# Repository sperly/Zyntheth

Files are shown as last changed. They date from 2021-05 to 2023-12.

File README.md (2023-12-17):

# Zynthethet
The Zyntheth will be a 4-6 operator 16 voices FM synthesis synth. It will have DIN-5 MIDI In, Thru and Out (from the Arpeggio). It will also have a USB-based Midi interface. There will also be support for Ethernet based RTP-MIDI.

It will have a stereo output (3.5mm plug) and it is powered by a regular micro-USB phone charger (500mA is enough). The user interface is a 3.5 inch touch LCD and 5 rotary encoders.

# Hardware
The hardware consists of 5 different pcb's:

The power board, takes the power from the micro-USB and converts it to 3.3v for other modules to run on.
The UI board, has the display and a connection for 1 encoder board with 5 encoders. It also has a Teensy 4.1 micro controller with 8Mb extra flash for graphics.
The Audio board, is the audio generator board with a Teensy 4.1 with 16Mb added PSRAM for additional effects usage.
The Interface board, has an Teensy 4.1 with ethernet interface added. This board takes care of all signals in and out from the Zyntheth (apart from the audio signals). It will also take care of arpeggio note generation.
Encoder board, a board with 5 rotary encoder and a button fitted to it. It has a SPI interface connection to the UI board.

# Functionality
4-6 operators (similar to DX9/DX7) FM synthesis in multiple algorithmic configuration
Individual envelope for each operator
Configurable detune, volume, panning for each operator
General envelope
Filter, 5-band parametric equlizer
Multiple effects: chorus, reverb, echo/delay, BitChrusher, Granular, etc.
Dual configurable LFO, either frequency, detune och volume
Configurable midi channel

# Todo
Add USB Audio output.

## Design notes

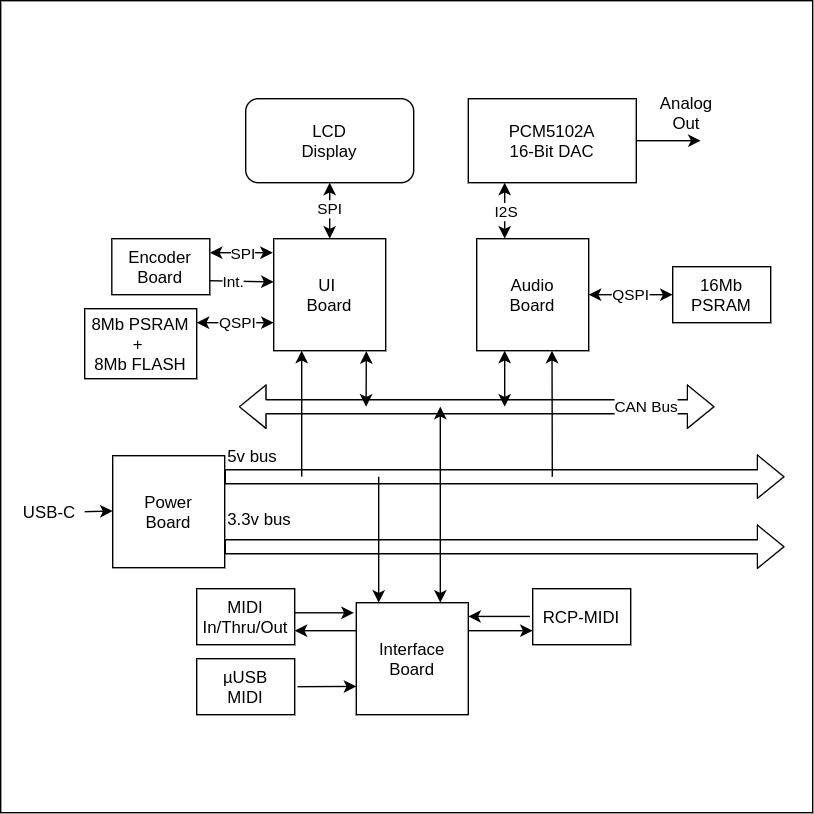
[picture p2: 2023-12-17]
Graphics/Zyntheth.png

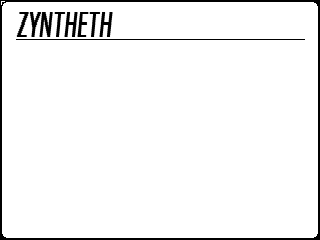
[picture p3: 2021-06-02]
Graphics/main.bmp

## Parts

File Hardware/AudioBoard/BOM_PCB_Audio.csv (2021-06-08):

ID | Name | Designator | Footprint | Quantity | Manufacturer Part | Manufacturer | Supplier | Supplier Part | Price | JLCPCB Part Class
1 | 2.2µF | C1,C2 | CASE-A_3216 | 2 | CL10A225KO8NNNC | SAMSUNG | LCSC | C23630 | 0.0092
2 | 100µF | C3,C4 | ECAP_5X5.4 | 2 | RVT1A101M0505 | HONOR | LCSC | C3347 | 0.041
3 | 1u | C6 | CASE-A_3216 | 1 | CL31B105KBHNNNE | SAMSUNG | LCSC | C1848 | 0.0386
4 | 0.1uF | C5,C7 | CASE-A_3216 | 2 | CC0603KRX7R9BB104 | YAGEO | LCSC | C14663 | 0.0041
5 | PJ-307G5 | CN1,CN2 | AUDIO-TH_PJ-307G5 | 2 | PJ-307G5 | XKB Enterprise | LCSC | C381128 | 0.1643 | Extended Part
6 | SS12 | D3 | SMA_L4.3-W2.6-LS5.2-RD | 1 | SS12 | MDD | LCSC | C2479 | 0.0354 | Extended Part
7 | Hole | HOL1,HOL2,HOL3,HOL4 | 3.5MM HOLE | 4
8 | 1X2 | J3 | HDR-TH_2P-P2.54-V | 1 | 210-91-02GB01 | PINREX | LCSC | C390678 | 0.0083
9 | Header-Female-2.54_1x11 | P1 | PIN_HEADER_STRAIGHT_1X11_PITCH2.54MM | 1 | Female header 2.54-1*11P | BOOMELE | LCSC | C52709 | 0.101
10 | Header-Male-2.54_1x3 | P2 | HDR-3X1/2.54 | 1 | Header-Male-2.54_1x3 | LCSC | LCSC | C49257 | 0.0171
11 | Header-Female-2.54_1x2 | P3,P4 | HDR-TH_2P-P2.54-V-M | 2 | 2.54-1*2PFemale | BOOMELE | LCSC | C49661 | 0.0321 | Extended Part
12 | 100k | R1,R7 | R0603 | 2 | CMFA104F4150HANT | FH | LCSC | C71448 | 0.0587
13 | 3k9 | R2,R3,R4,R6 | R0603 | 4 | 0603WAF3901T5E | UniOhm | LCSC | C23018 | 0.0015
14 | 220 | R9 | R0603 | 1 | 0603WAF2200T5E | UniOhm | LCSC | C22962 | 0.0015
15 | Teensy 4.1 | U1 | TEENSY 4.1 | 1 | TEENSY41 | pjrc | pimoroni | TEENSY41
16 | LM4808MX/NOPB | U2 | SOIC-8_L4.9-W3.9-P1.27-LS6.0-BL-2 | 1 | LM4808MX/NOPB | Texas Instruments | LCSC | C141374 | 0.6925 | Extended Part

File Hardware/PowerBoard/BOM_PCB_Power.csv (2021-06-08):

ID | Name | Designator | Footprint | Quantity | Manufacturer Part | Manufacturer | Supplier | Supplier Part | Price | JLCPCB Part Class
1 | 1u | C1,C2 | CASE-A_3216 | 2 | CL21B105KBFNNNE | SAMSUNG | LCSC | C28323 | 0.0143
2 | HDR-F-2.54_2x2 | H1 | HDR-F-2.54_2X2 | 1 |  |  | LCSC | C239342 | 0.0854
3 | HDR-F-2.54_1x2 | H2,H3,H4,H5,H6,H7 | HDR-F-2.54_1X2 | 6 |  |  | LCSC | C49661 | 0.0321
4 | Hole | HOL1,HOL2,HOL3,HOL4 | 3.5MM HOLE | 4
5 | LM1117MPX-3.3/NOPB | U2 | SOT-223-3_L6.5-W3.4-P2.30-LS7.0-BR | 1 | LM1117MPX-3.3/NOPB | TI | LCSC | C9662 | 0.5104 | Extended Part
6 | TYPE-C-31-M-17 | USB1 | USB-C-SMD_10P-P1.00-L6.8-W8.9 | 1 | TYPE-C-31-M-17 | Korean Hroparts Elec | LCSC | C283540 | 0.2146 | Extended Part

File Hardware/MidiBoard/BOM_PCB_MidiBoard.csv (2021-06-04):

ID | Name | Designator | Footprint | Quantity | Manufacturer Part | Manufacturer | Supplier | Supplier Part | Price | JLCPCB Part Class
1 | 100n | C1 | C0603 | 1 | CC0603KRX7R9BB104 | YAGEO | LCSC | C14663 | 0.0041
2 | 100n | C2,C3 | C0603 | 2 | CC0603KRX7R9BB104 | YAGEO | LCSC | C14663 | 0.0041
3 | 100n | C4 | C0603 | 1 | CC0603KRX7R9BB104 | YAGEO | LCSC | C14663 | 0.0041
4 | 1N4004 | D1 | SOD-123_L2.8-W1.8-LS3.7-RD | 1 | 1N4004W | Jingdao | LCSC | C162734 | 0.0104
5 | USBLC6-2SC6 | D2 | SOT-23-6_L2.9-W1.6-P0.95-LS2.8-BR | 1 | USBLC6-2SC6 | STMicroelectronics | LCSC | C7519 | 0.3978 | Extended Part
6 | SS12 | D3 | SMA_L4.3-W2.6-LS5.2-RD | 1 | SS12 | MDD | LCSC | C2479 | 0.0354 | Extended Part
7 | HDR-F-2.54_1x2 | H1 | HDR-F-2.54_1X2 | 1 | 826629-2 | TE Connectivity | LCSC | C86471 | 0.1458
8 | Hole | HOL1,HOL2,HOL3,HOL5,HOL6 | 3.5MM HOLE | 5
9 | 1X2 | J1,J2 | HDR-TH_2P-P2.54-V | 2 | 826629-2 | TE Connectivity | LCSC | C86471 | 0.1458
10 | LED-0603_R | LED1 | LED0603_RED | 1 | 19-217/R6C-AL1M2VY/3T | EVERLIGHT(台湾亿光) | LCSC | C72044 | 0.0157
11 | 330 | R1 | R0603 | 1 | 0603WAF3300T5E | UniOhm | LCSC | C23138 | 0.0015
12 | 220 | R2,R3,R5,R7,R8,R9 | R0603 | 6 | 0603WAF2200T5E | UniOhm | LCSC | C22962 | 0.0015
13 | 470 | R4,R10 | R0603 | 2 | 0603WAF4700T5E | UniOhm | LCSC | C23179 | 0.0017
14 | 4k7 | R6 | R0603 | 1 | 0603WAF4701T5E | UniOhm | LCSC | C23162 | 0.0014
15 | 13F-60FGYDPNW2NL | RJ1 | RJ45-TH_13F-60FGYDPNW2NL | 1 | 13F-60FGYDPNW2NL | YDS | LCSC | C115955 | 2.1964 | Extended Part
16 | MIDI OUT | U2 | MIDI | 1
17 | 1 | U3 | TEENSY4.1 - KB | 1 | Teensy4.1 | PJRC
18 | 74HCT14D,653 | U4 | SOIC-14_L8.7-W3.9-P1.27-LS6.0-BL | 1 | 74HCT14D,653 | Nexperia | LCSC | C5967 | 0.1389 | Extended Part
19 | 6N138-L | U5 | DIP-8_L9.7-W6.4-P2.54-LS7.6-BL | 1 | 6N138-L | Lite-On | LCSC | C571211 | 0.422 | Extended Part
20 | MIDI IN | U6 | MIDI | 1
21 | MIDI THRU | U7 | MIDI | 1
22 | MICRO XNJ ZB | USB1 | MICRO-USB-SMD_MICRO-XNJ-ZB | 1 | MICRO XNJ ZB | SHOU HAN(首韩) | LCSC | C668587 | 0.0587

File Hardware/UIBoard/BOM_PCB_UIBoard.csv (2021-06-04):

ID | Name | Designator | Footprint | Quantity | Manufacturer Part | Manufacturer | Supplier | Supplier Part | Price | JLCPCB Part Class | Paste Type
1 | CR1220-2ZX | BT1 | BAT-SMD_CR1220-2ZX | 1 | CR1220-2ZX | Q&J | LCSC | C969906 | 0.2763 | Extended Part | Extended Part
2 | SS12 | D1 | SMA_L4.3-W2.6-LS5.2-RD | 1 | SS12 | MDD | LCSC | C2479 | 0.0354 | Extended Part
3 | Header-Male-2.54_2x5 | H1 | HDR-TH_10P-P2.54-V-R2-C5-S2.54 | 1 | IDC Box 2X5 2.54MM | BOOMELE | LCSC | C9140 | 0.0865
4 | Header-Female-2.54_1x4 | H2 | HDR-4X1/2.54 | 1 | Header-Female-2.54_1x4 | ReliaPro | LCSC | C124413 | 0.0943
5 | J-Header-Male-2.54_1x2 | H3,H4 | HDR-2X1/2.54 | 2 | 826629-2 | TE Connectivity | LCSC | C86471 | 0.1458
6 | 1X2 | H5 | HDR-TH_2P-P2.54-V | 1 | 210-91-02GB01 | PINREX | LCSC | C390678 | 0.0083
7 | M11 | H6 | 1X11_LOCK | 1
8 | Hole | HOL1,HOL2,HOL3,HOL4 | 3.5MM HOLE | 4
9 | 220 | R1 | R0603 | 1 | 0603WAF2200T5E | UniOhm | LCSC | C22962 | 0.0015
10 | 10k | R2 | R0603 | 1 | 0603WAF1002T5E | UniOhm | LCSC | C25804 | 0.0014
11 | teensy_Teensy3.6_1 | U1 | TEENSY35_36 | 1

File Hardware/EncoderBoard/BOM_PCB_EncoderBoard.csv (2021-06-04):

ID | Name | Designator | Footprint | Quantity | Manufacturer Part | Manufacturer | Supplier | Supplier Part | Price | JLCPCB Part Class
1 | 10nF | C1,C2,C3,C4,C5,C6,C7,C8,C9,C10 | C0603 | 10 | CL10B103JB8NNNC | SAMSUNG | LCSC | C7248 | 0.0084
2 | 0.1u | C11 | C0603 | 1 | CL10B104JB8NNNC | SAMSUNG | LCSC | C24452 | 0.0086
3 | Header-Male-2.54_2x5 | H1 | HDR-TH_10P-P2.54-V-R2-C5-S2.54 | 1 | IDC Box 2.54mm 2X5P | BOOMELE | LCSC | C5665 | 0.0652
4 | 10k | R1,R2,R3,R4,R5,R6,R7,R8,R9,R10,R11,R12,R13,R14,R15,R16,R17,R18,R19,R20,R21,R22,R23,R24,R25,R26,R27 | R0603 | 27 | SDNT1608X103F3450FTF | Sunlord | LCSC | C95953 | 0.0386
5 | PEC11R-4015F-S0024 | SW1,SW2,SW3,SW4,SW5 | SW-TH_PEC11R-4XXXF-SXXXX | 5 | PEC11R-4015F-S0024 | BOURNS | LCSC | C143789 | 1.8394 | Extended Part
6 | K2-1102SP-C4SC-04 | SW6 | KEY-SMD_4P-L6.0-W6.0-P4.50-LS9.5-BL | 1 | K2-1102SP-C4SC-04 | HRO | LCSC | C127509 | 0.0479 | Extended Part
7 | MCP23S17-E/ML | U2 | QFN-28_L6.0-W6.0-P0.65-BL-EP | 1 | MCP23S17-E/ML | MICROCHIP | LCSC | C147896 | 3.071 | Extended Part

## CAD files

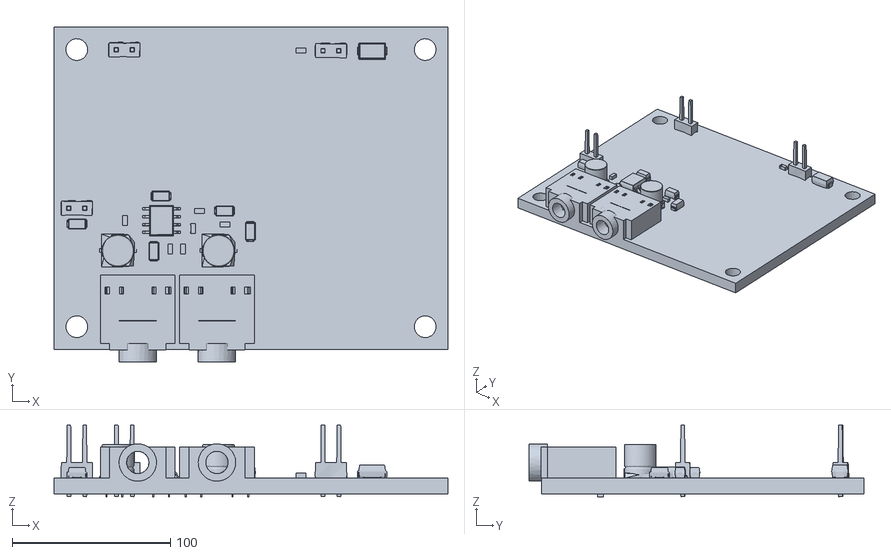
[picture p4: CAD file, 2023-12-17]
Hardware/AudioBoard/PCB_Zyntheth-Audio.stl
248.8 x 211.8 x 45.2

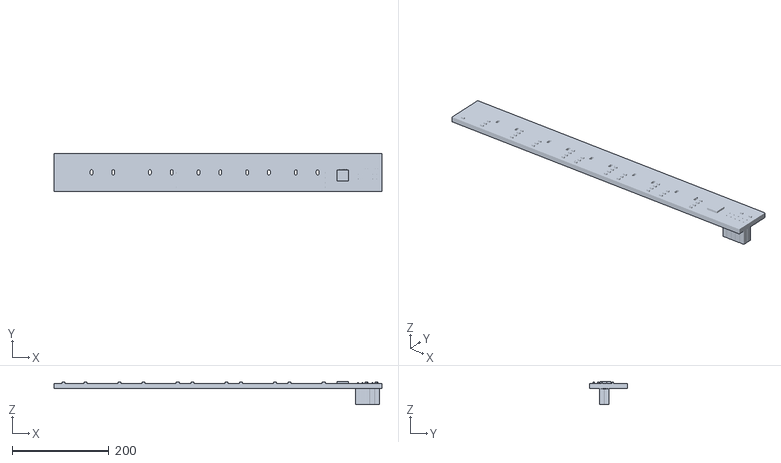
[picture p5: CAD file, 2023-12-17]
Hardware/EncoderBoard/PCB_EncoderBoard.stl
676.8 x 77.5 x 47.5

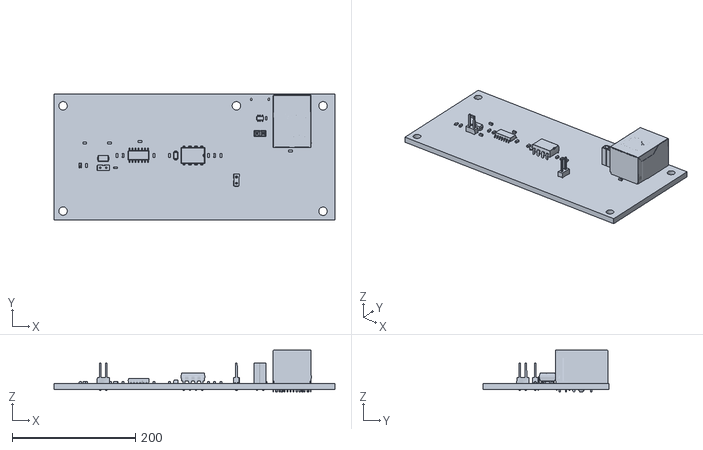
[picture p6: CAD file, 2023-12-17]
Hardware/MidiBoard/OBJ_PCB_Zyntheth-Midi-teensy.obj
455.8 x 204.8 x 67.6

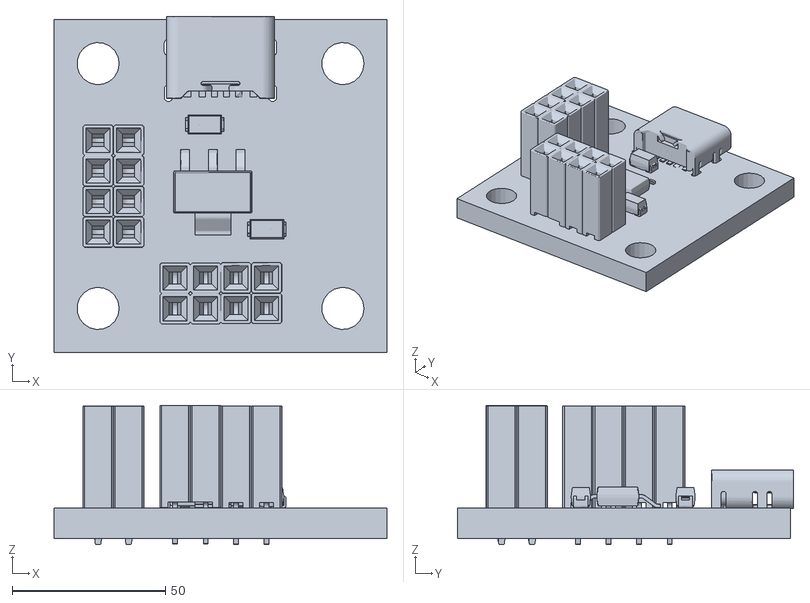
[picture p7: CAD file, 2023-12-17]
Hardware/PowerBoard/OBJ_PCB_Zynthet-Power.obj
108.8 x 109.8 x 45.5

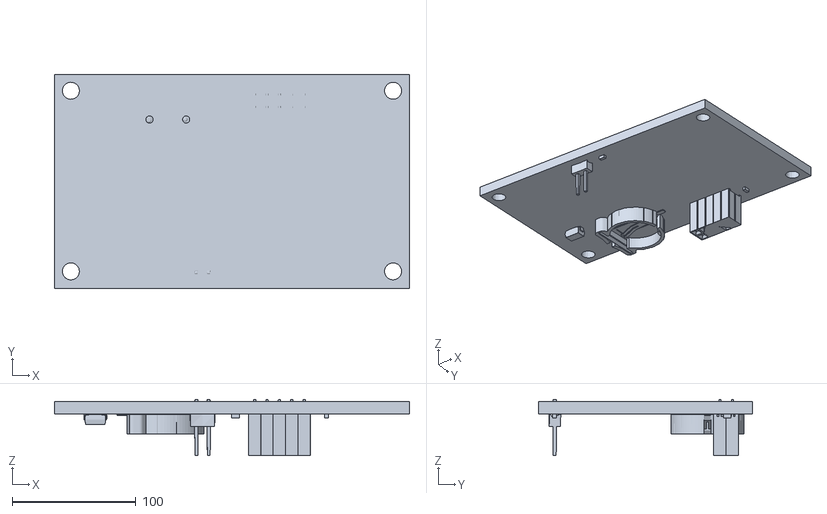
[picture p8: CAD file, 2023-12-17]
Hardware/UIBoard/PCB_UIBoard.stl
286.3 x 172.8 x 45.3

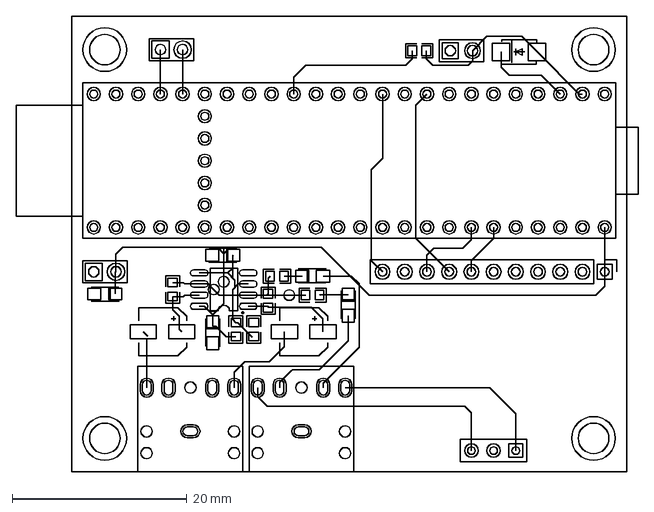
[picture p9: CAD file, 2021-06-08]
Hardware/AudioBoard/PCB_Audio.dxf
71.1 x 52.1 mm

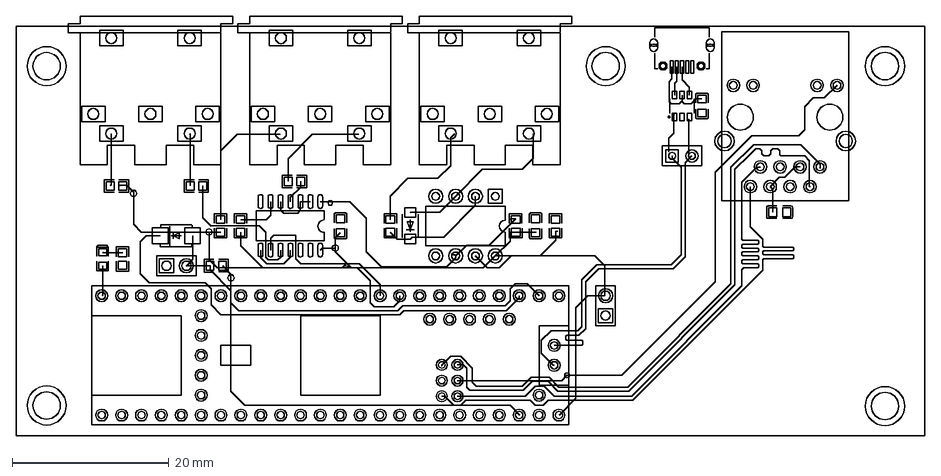
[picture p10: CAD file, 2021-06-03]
Hardware/MidiBoard/PCB_MidiBoard.dxf
116.1 x 53.6 mm

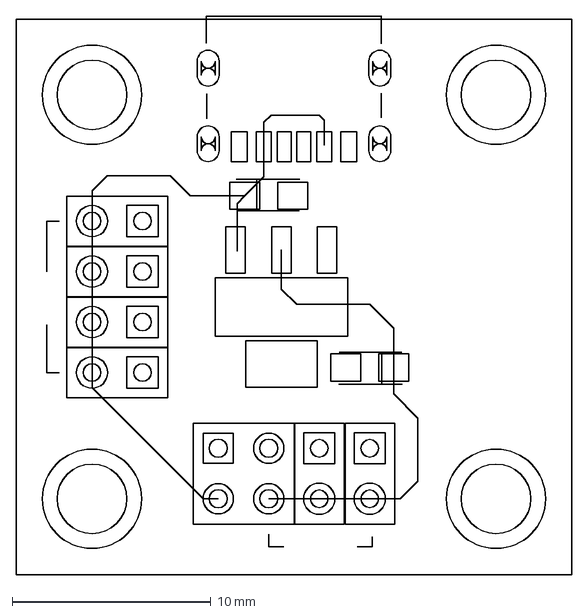
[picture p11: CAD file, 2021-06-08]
Hardware/PowerBoard/PCB_Power.dxf
27.9 x 28.1 mm

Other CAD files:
Hardware/AudioBoard/OBJ_PCB_Zyntheth-Audio.obj
Hardware/EncoderBoard/OBJ_PCB_EncoderBoard.obj
Hardware/MidiBoard/PCB_Zyntheth-Midi-teensy.stl
Hardware/PowerBoard/PCB_Zynthet-Power.stl
Hardware/UIBoard/OBJ_PCB_UIBoard.obj
Hardware/EncoderBoard/PCB_EncoderBoard.dxf
Hardware/UIBoard/PCB_UIBoard.dxf

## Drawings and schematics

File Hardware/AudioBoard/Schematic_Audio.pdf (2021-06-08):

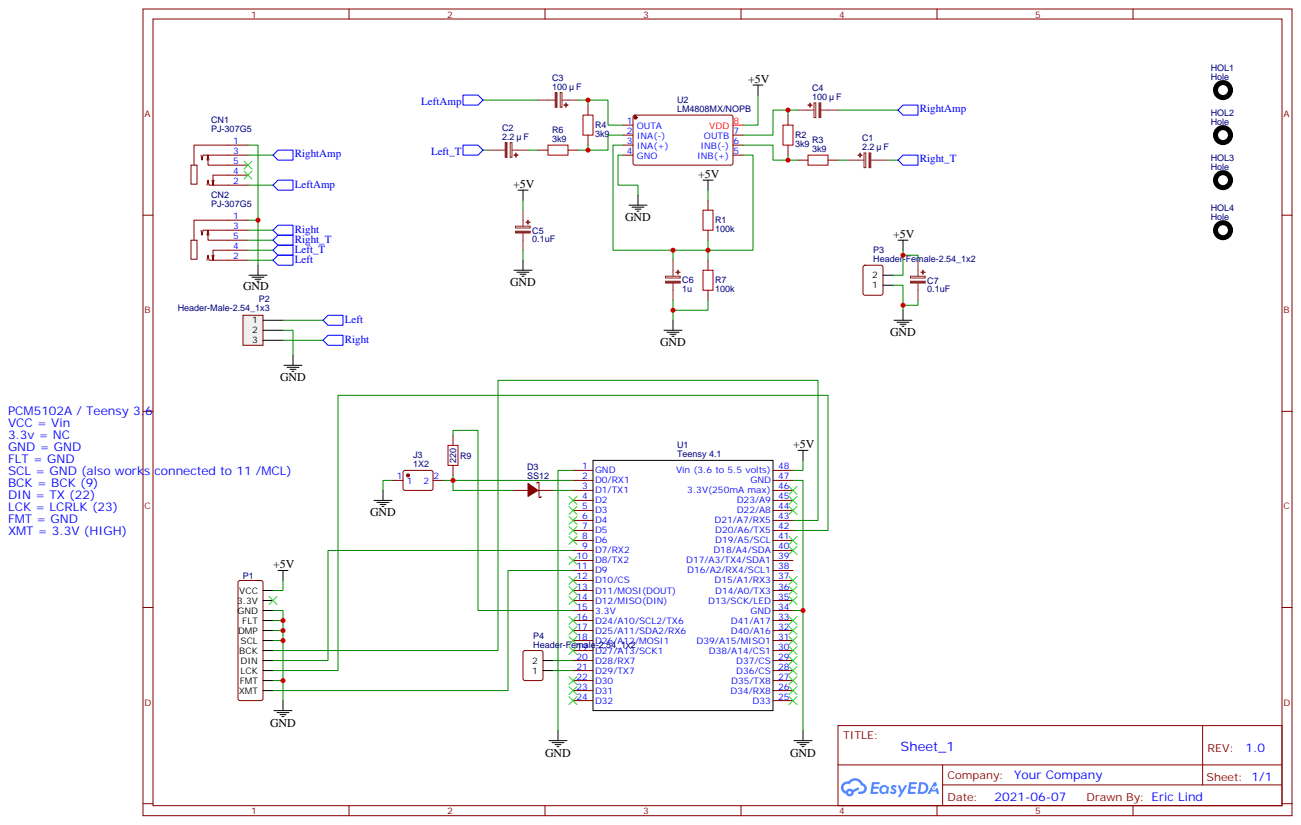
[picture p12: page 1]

PCM5102A / Teensy 3.6
VCC = Vin
GND = GND
FLT = GND
SCL = GND (also works connected to 11 /MCL)
BCK = BCK (9)
DIN = TX (22)
LCK = LCRLK (23)
FMT = GND
XMT = 3.3V (HIGH)

Drawn By: Eric Lind

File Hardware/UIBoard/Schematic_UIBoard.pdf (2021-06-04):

## Hole

## HOL1

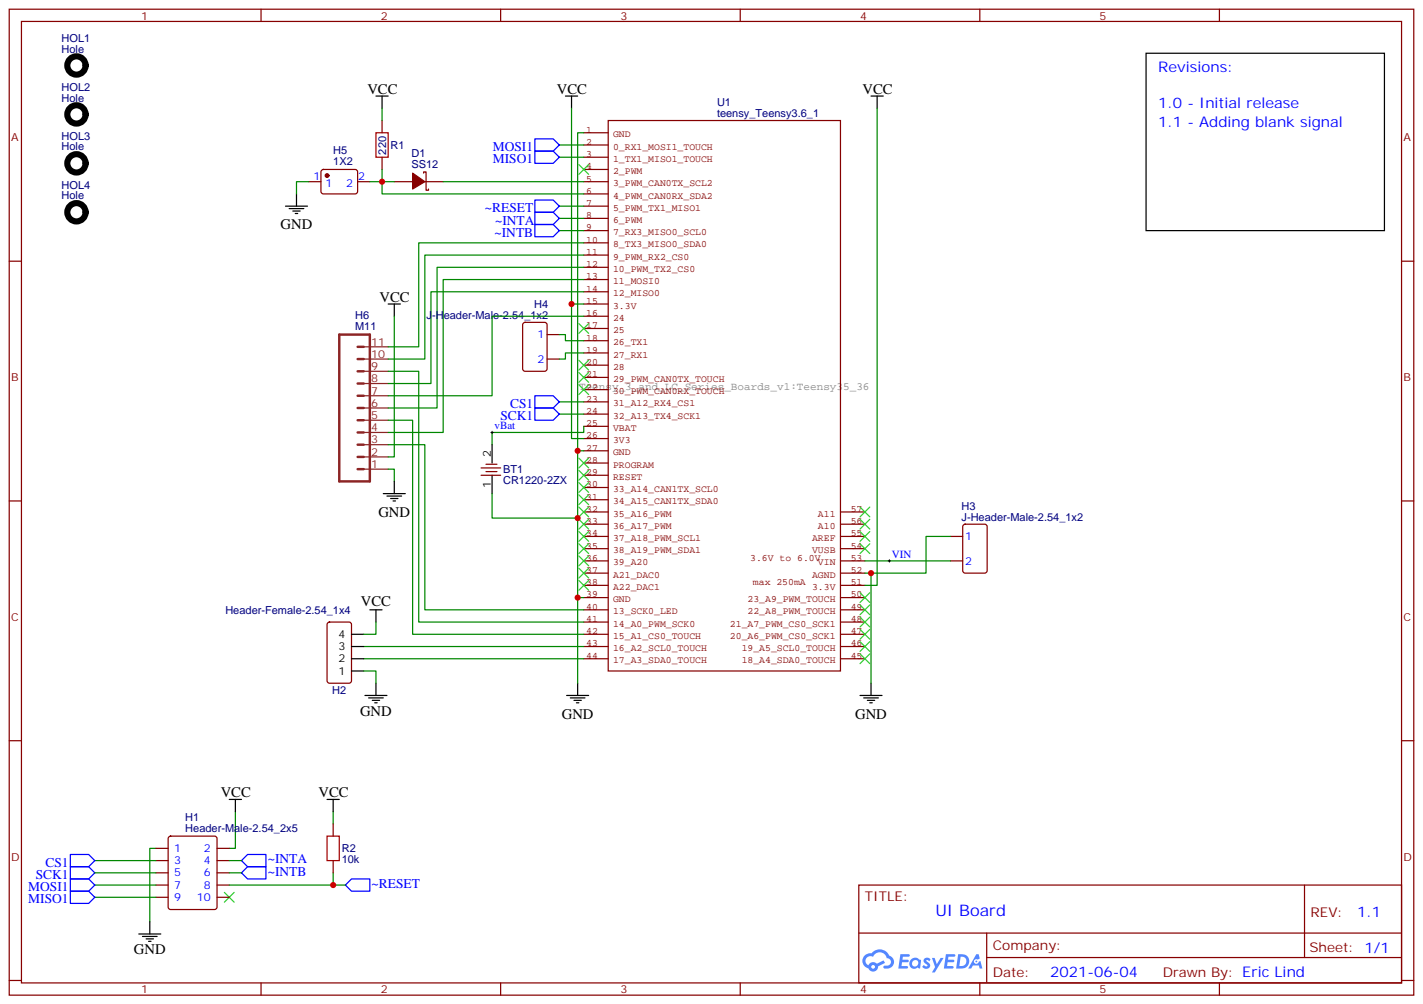
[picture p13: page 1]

Drawn By: Eric Lind

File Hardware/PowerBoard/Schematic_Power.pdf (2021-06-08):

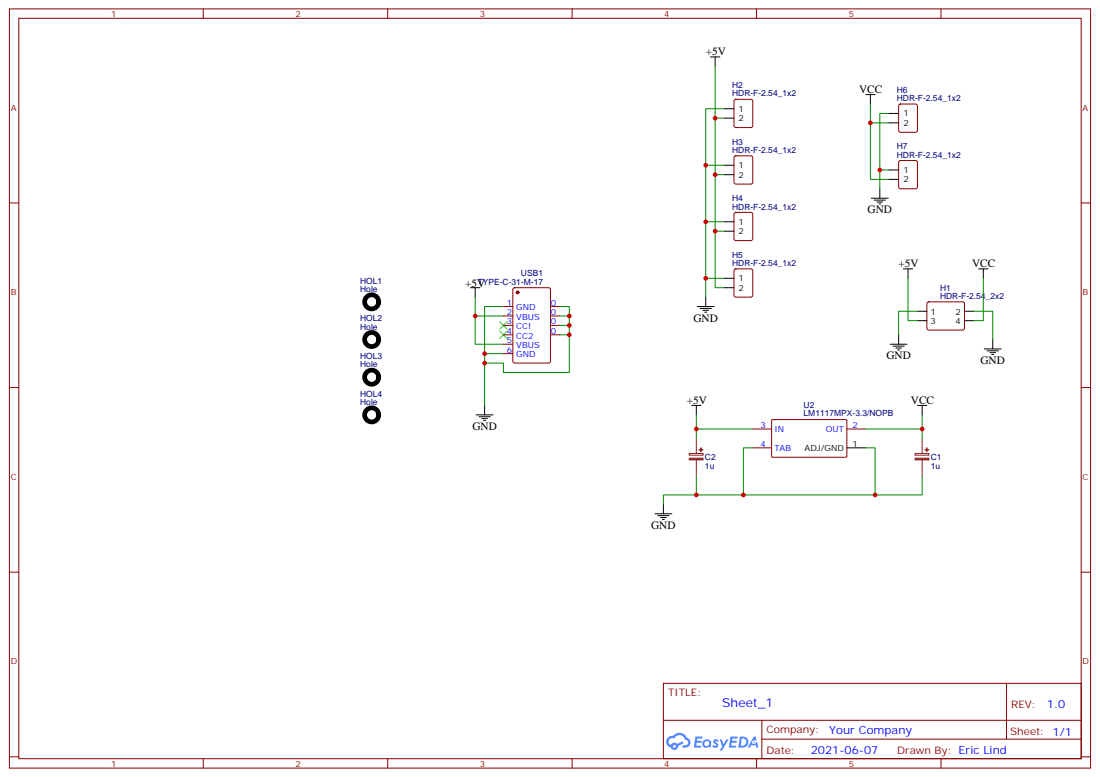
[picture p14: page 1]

Drawn By: Eric Lind

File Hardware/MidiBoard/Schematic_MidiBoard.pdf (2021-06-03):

## 74HCT14D,653

U4

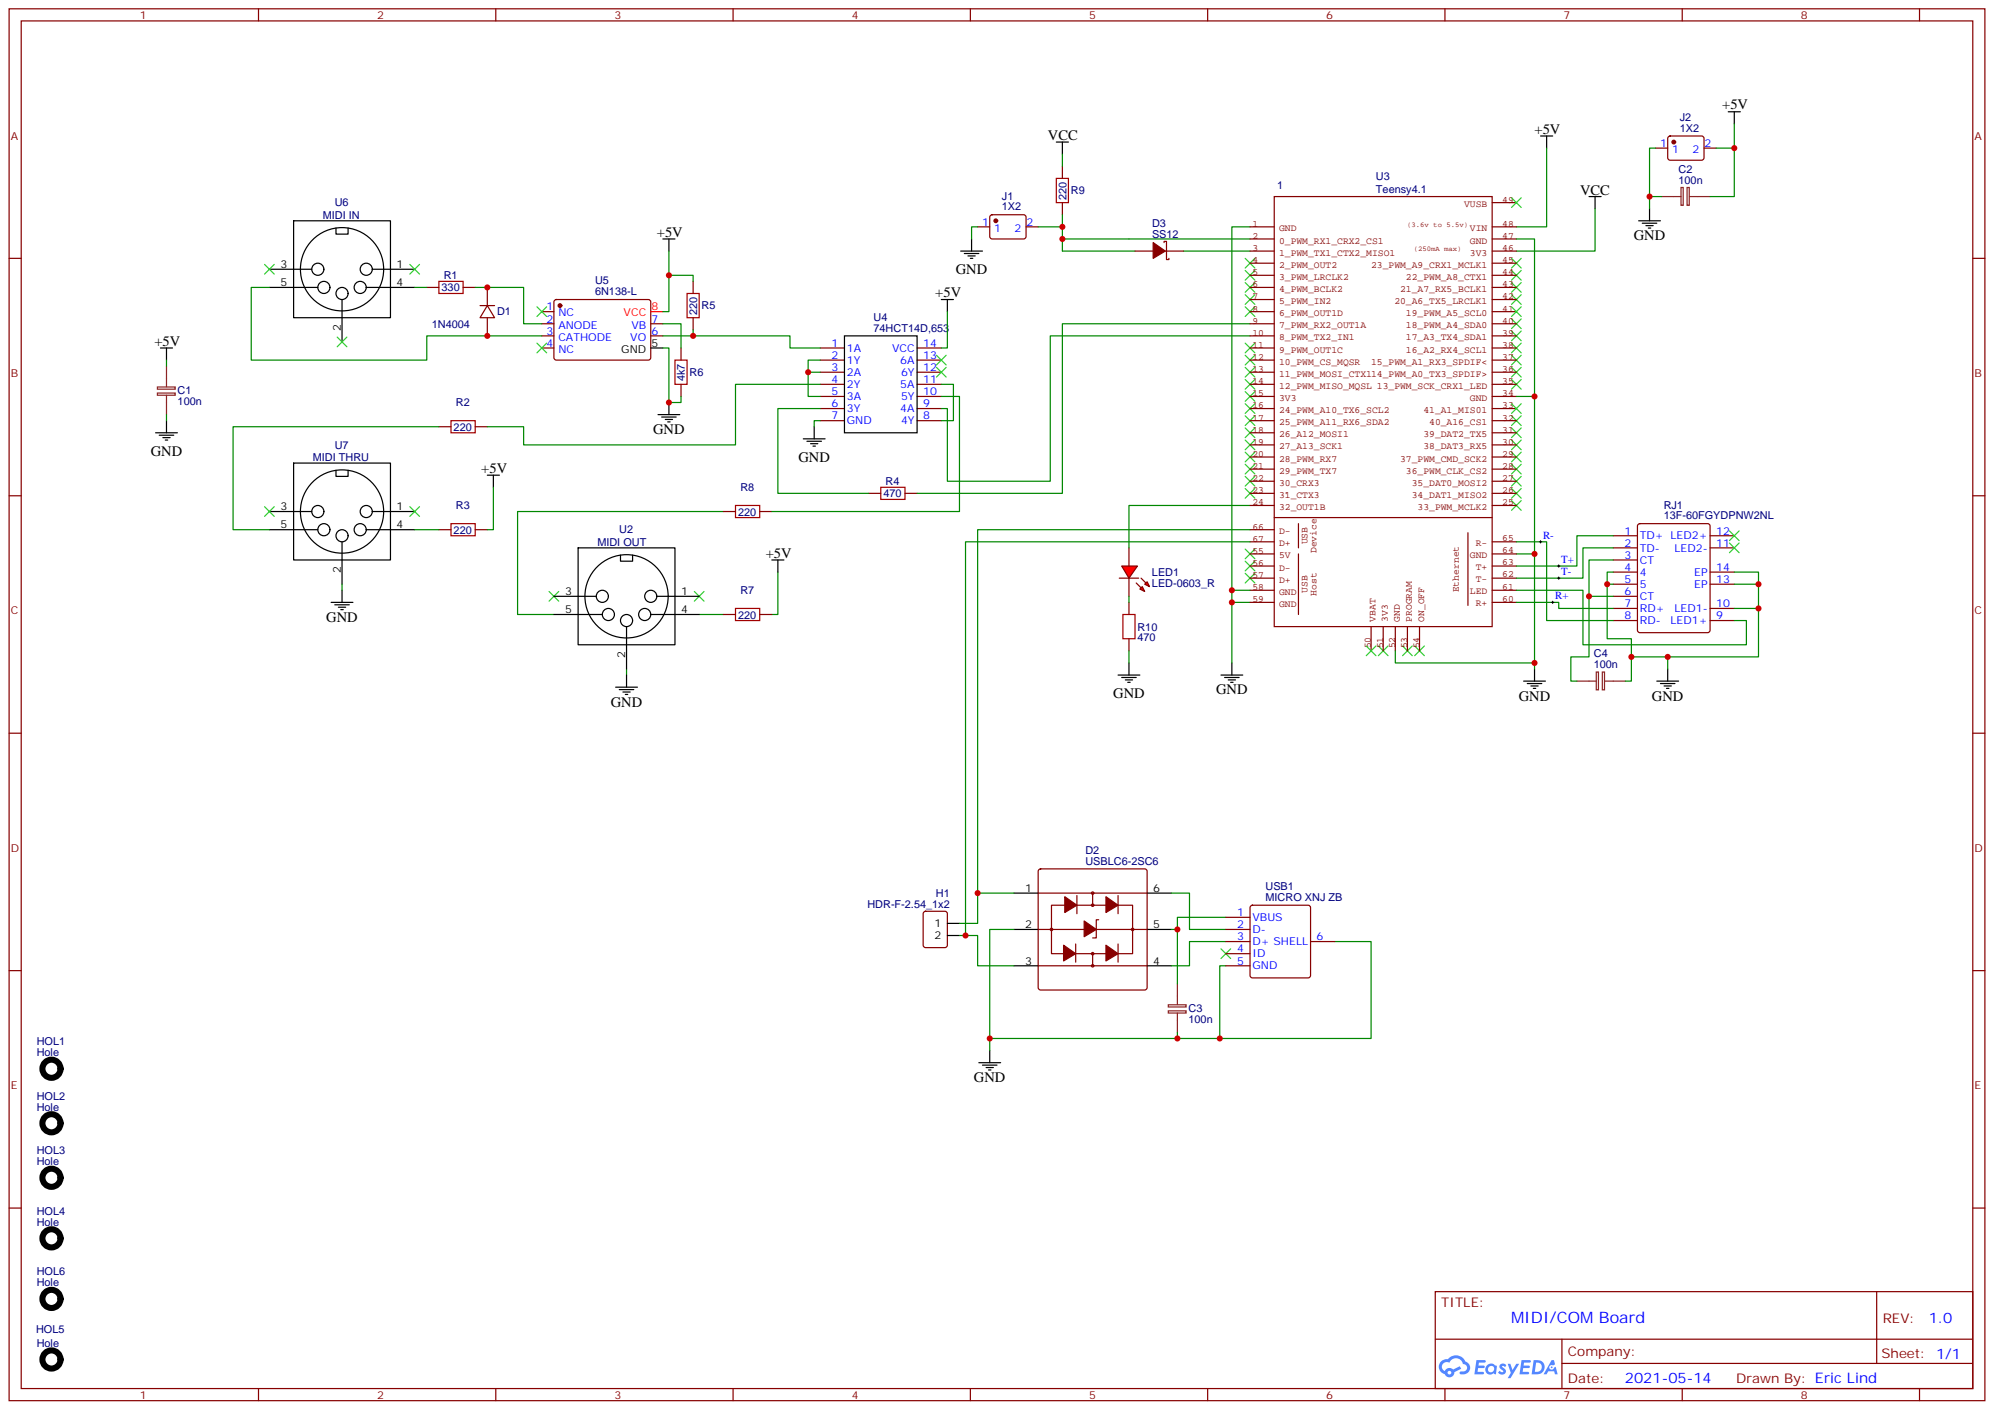
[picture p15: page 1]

Drawn By: Eric Lind

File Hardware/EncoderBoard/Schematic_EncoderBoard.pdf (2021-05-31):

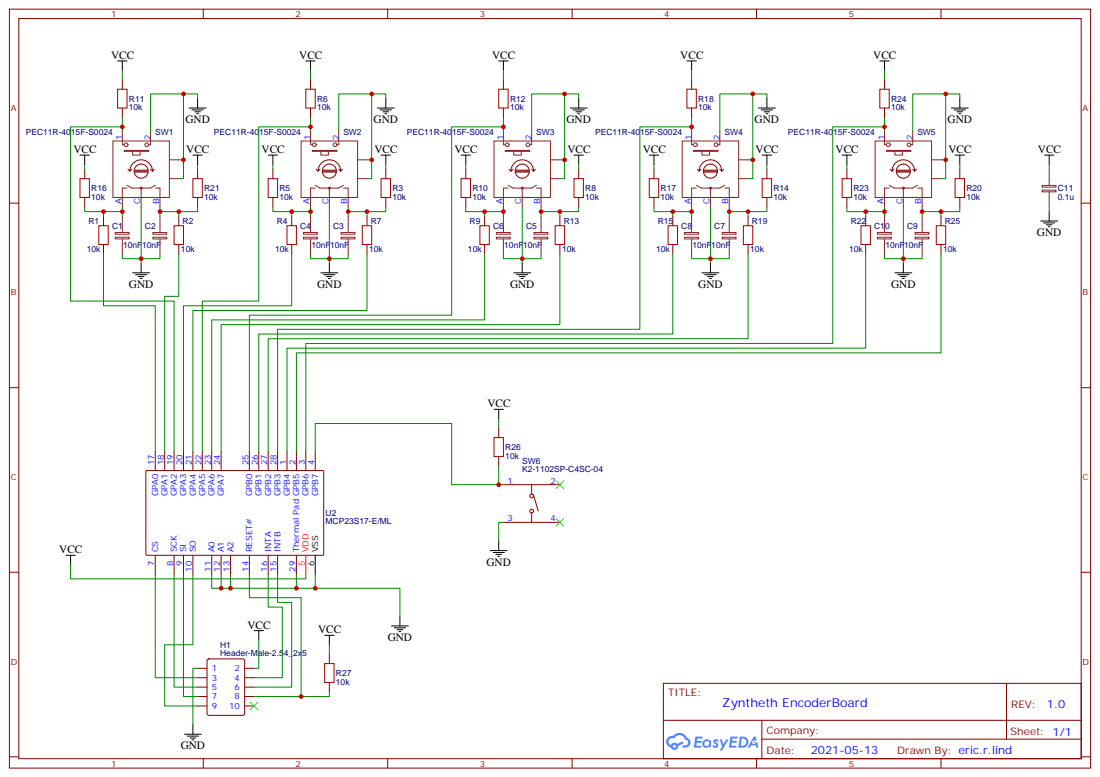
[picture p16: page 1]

Drawn By: eric.r.lind

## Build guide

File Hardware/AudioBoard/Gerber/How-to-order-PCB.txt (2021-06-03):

How to Order PCB

Please refer to:
https://docs.easyeda.com/en/PCB/Order-PCB

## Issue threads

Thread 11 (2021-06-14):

Bord bring up

sperly, 2021-06-14:
When all boards have arrived the initial board bring up need to happaen. In this includes to find bugs in board layouts and fix design issues:

* Add connection for BCK signal to display to Teensy for enabling screen saver.

sperly, 2021-12-08:
Found missing pin on UI-board. Added in coming revision of board.

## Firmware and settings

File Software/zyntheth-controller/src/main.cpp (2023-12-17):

#include <XPT2046_Touchscreen.h>
#include "Arduino.h"
#include "ILI9341_t3n.h"
#include "Metro.h"
#include "SdFat.h"
#include "com/com.hpp"
#include "config.hpp"
#include "encoder.hpp"
#include "log.hpp"
#include "mcp23s17.hpp"
#include "menuhandler.hpp"
#include "valuecontainer.hpp"

#define ENC_INT_A 24
#define CS_PIN 31

MCP23S17 gpio;

#define TCS_PIN 9
#define TIRQ_PIN 8
XPT2046_Touchscreen ts(TCS_PIN, TIRQ_PIN);

Encoder encoder[ENCODERS];
ValueContainer vc{};

short lightState      = 0;
short lcdBackLightPin = 24;

MenuHandler menuHandler{};

Metro sleepTimer = Metro(LCD_TIMEOUT);
bool sleeping    = false;

bool signalsChanged = false;

Com com{vc};

#define SD_FAT_TYPE 3
//const uint8_t SD_CS_PIN = SDCARD_SS_PIN;
#define SPI_CLOCK SD_SCK_MHZ(50)
#define SD_CONFIG SdioConfig(FIFO_SDIO)

void resetSleepTimer()
{
    if (sleeping == true)
    {
        digitalWrite(lcdBackLightPin, HIGH);
        vc.lcdHandler.sleep(false);
        sleeping = false;
        sleepTimer.reset();
        LOG_DEBUG("LCD Wake Up");
    }
    else
    {
        sleepTimer.reset();
    }
}

void checkEncoders()
{
    uint8_t portA = gpio.ReadPortA();
    uint8_t portB = gpio.ReadPortB();
    uint16_t pos  = portA | ((uint16_t)portB << 8);

    bool updated = false;

    for (int count = 0; count < 5; ++count)
    {
        vc.Controls.update[count] = encoder[count].PushState((char)((pos >> (count * 3)) & 0b00000011));
        if (vc.Controls.update[count])
        {
            vc.Controls.localSteps[count] += encoder[count].GetSteps();
            if (vc.Controls.localSteps[count] != 0)
            {
                menuHandler.HandleMenuAction(count, vc.Controls.localSteps[count]);
                updated = true;
            }
            vc.Controls.localSteps[count] = 0;
        }

        uint8_t bPress = ((char)((pos >> (count * 3)) & 0b00000100) >> 2);
        if (bPress != vc.Controls.buttonpress[count])
        {
            LOG_DEBUG("Encoder", "Button: %d - %d", count, bPress);
            menuHandler.HandleMenuAction(count + ENCODERS, bPress);
            vc.Controls.buttonpress[count] = bPress;
            updated                        = true;
        }
    }
    uint8_t bPress = ((char)((pos >> 8) & 0b10000000) >> 7);
    if (bPress != vc.Controls.buttonpress[ENCODERS])
    {
        LOG_DEBUG("Encoder", "Button: %d - %d", ENCODERS, bPress);
        menuHandler.HandleMenuAction(ENCODERS + ENCODERS, bPress);
        vc.Controls.buttonpress[ENCODERS] = bPress;
        updated                           = true;
    }

    if (updated)
    {
        signalsChanged = true;
        resetSleepTimer();
    }
}

void setup()
{
    Serial.begin(115200);
    // while (!Serial)
    //     ;

    Serial.printf("\n\r\n\r\n\r");
    LOG_DEBUG("Starting ZYNTHETH...");

    for (int count = 0; count < 5; ++count)
    {
        encoder[count] = Encoder();
        encoder[count].Reset();
    }

    LOG_DEBUG("Initializing SD...");

    // if (!SD.begin(BUILTIN_SDCARD))
    // {
    //     LOG_DEBUG("... initialization failed!");
    //     return;
    // }

    if (!vc.sd.begin(SD_CONFIG))
    {
        //sd.initErrorHalt(&Serial);
        LOG_DEBUG("... initialization failed!");
        return;
    }

    LOG_DEBUG("... initialization done!");

    gpio.Init(CS_PIN);
    gpio.SetPortDirection(PORT_A, PORT_INPUT);
    gpio.SetPortDirection(PORT_B, PORT_INPUT);
    //attachInterrupt(ENC_INT_A, ISR_EncIntA, FALLING);

    LOG_DEBUG("Initializing LCD...");
    pinMode(lcdBackLightPin, OUTPUT);
    digitalWrite(lcdBackLightPin, LOW);

    vc.lcdHandler.begin();
    vc.lcdHandler.setRotation(1);
    vc.lcdHandler.fillScreen(ILI9341_WHITE);

    ts.begin();
    ts.setRotation(1);
    LOG_DEBUG("Initialization LCD done.");

    menuHandler.Init(vc);
    digitalWrite(lcdBackLightPin, HIGH);
    sleepTimer.reset();

    LOG_DEBUG("Initializing CAN...");
    Can0.begin(1000000);
    LOG_DEBUG("Initialization CAN done.");
}

void loop()
{
    checkEncoders();
    if (!sleeping && sleepTimer.check())
    {
        vc.lcdHandler.sleep(true);
        digitalWrite(lcdBackLightPin, LOW);
        sleeping = true;
        LOG_DEBUG("LCD Sleep");
    }
    if (signalsChanged)
    {
        com.Send();
        signalsChanged = false;
    }

    if (ts.tirqTouched())
    {
        if (ts.touched())
        {
            resetSleepTimer();
            TS_Point p = ts.getPoint();
            Serial.print("Pressure = ");
            Serial.print(p.z);
            Serial.print(", x = ");
            Serial.print(p.x);
            Serial.print(", y = ");
            Serial.print(p.y);
            delay(30);
            Serial.println();
        }
    }
}

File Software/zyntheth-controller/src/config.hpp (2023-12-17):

#define ENCODERS 5
#define BUTTONS 6
#define OSCILLATORS 4
#define WAVEFORMS 2

#define LCD_TIMEOUT 60000
#define LCD_CS 14
#define LCD_DC 10
#define LCD_RST 15
#define LCD_MOSI 11
#define LCD_SCLK 13
#define LCD_MISO 12

#define HW_VER_MAJOR 1
#define HW_VER_MINOR 0
#define HW_VER_PATCH 1

#define SW_VER_MAJOR 1
#define SW_VER_MINOR 0
#define SW_VER_PATCH 1

#define HEADER_HEIGHT 32
#define HEADER_WIDTH 160

#define DATA_X 15
#define DATA_Y 40
#define DATA_VALUE_X 185
#define DATA_SPACING 20

#define FOOTER_Y 210

#define DELAY_MIN 0.0
#define DELAY_DEF 0.0
#define DELAY_MAX 11800
#define ATTACK_MIN 0.0
#define ATTACK_DEF 10.5
#define ATTACK_MAX 11880.0
#define HOLD_MIN 0.0
#define HOLD_DEF 2.5
#define HOLD_MAX 11800.0
#define DECAY_MIN 0.0
#define DECAY_DEF 35.0
#define DECAY_MAX 11880.0
#define SUSTAIN_MIN 0.0
#define SUSTAIN_DEF 0.75
#define SUSTAIN_MAX 1.0
#define RELEASE_MIN 0.0
#define RELEASE_DEF 100
#define RELEASE_MAX 11880.0

#define WAVEFORM_SINE 0
#define WAVEFORM_SAWTOOTH 1
#define WAVEFORM_SAWTOOTH_REVERSE 2
#define WAVEFORM_SQUARE 3
#define WAVEFORM_TRIANGLE 4
#define WAVEFORM_TRIANGLE_VARIABLE 5
#define WAVEFORM_ARBITRARY 6
#define WAVEFORM_PULSE 7
#define WAVEFORM_SAMPLE_HOLD 8

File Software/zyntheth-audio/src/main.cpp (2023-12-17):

#include "Arduino.h"
#include "config.hpp"
#include "midi.hpp"
#include "voice.hpp"
#include <Audio.h>
#include <memory>
#include <usb_audio.h>
#include <vector>

AudioControlSGTL5000 sgtl5000_1;
AudioOutputI2S i2s1;
AudioOutputUSB usbAudioOut;

//Calculate and design for scalability
Voice voices[POLYPHONY];

//Calculate and designa for scalability
//AudioMixer4 voiceMixers[MAIN_MIXERS];
DMAMEM std::vector<std::unique_ptr<AudioConnection>> patchcords;

void setupVoices()
{
    for (int voice = 0; voice < POLYPHONY; ++voice)
    {
        voices[voice].SetAlgorithm(1);

        for (int op = 0; op < OPERATORS; ++op)
        {
            voices[voice].SetAmplitude(op, 0.5);
            voices[voice].SetDetune(op, (op * 10));
            voices[voice].SetDelay(op, 0);
            voices[voice].SetAttack(op, 10);
            voices[voice].SetHold(op, 10);
            voices[voice].SetDecay(op, 20);
            voices[voice].SetSustain(op, 0.7);
            voices[voice].SetRelease(op, 800);
            voices[voice].SetFMod(op, 1);
        }
        voices[voice].Balance(50);
        voices[voice].Volume(0.7);

        voices[voice].SetWaveform(0, WAVEFORM_TRIANGLE);
        voices[voice].SetWaveform(1, WAVEFORM_SINE);
        voices[voice].SetWaveform(0, WAVEFORM_SQUARE);
        voices[voice].SetWaveform(0, WAVEFORM_SAWTOOTH);
    }
}

void setupMidi()
{
}

AudioMixer4 mixer_l{};
AudioMixer4 mixer_r{};

AudioConnection top2 = AudioConnection(mixer_l, 0, usbAudioOut, 0);
AudioConnection top3 = AudioConnection(mixer_r, 0, usbAudioOut, 1);

void MakeConnection()
{
    for (int voice = 0; voice < POLYPHONY; ++voice)
    {
        patchcords.push_back(std::make_unique<AudioConnection>(voices[voice].GetOutputL(), 0, mixer_l, voice));
        patchcords.push_back(std::make_unique<AudioConnection>(voices[voice].GetOutputR(), 0, mixer_r, voice));
    }
}

void ClearConnections()
{
    patchcords.clear();
}

void myNoteOn(uint8_t chan, uint8_t note, uint8_t vel)
{
    Serial.println("Note on: ");
    voices[0].PlayNote(note);
}

void myNoteOff(uint8_t chan, uint8_t note, uint8_t vel)
{
    Serial.println("Note on: ");
    voices[0].StopNote(note);
}

void setup()
{
    usbMIDI.setHandleNoteOn(myNoteOn);
    usbMIDI.setHandleNoteOff(myNoteOff);
    usbMIDI.begin();

    pinMode(LED_BUILTIN, OUTPUT);

    Serial.begin(115200);

    //while (!Serial) ; // wait for Arduino Serial Monitor

    delay(300);
    Serial.println("---* ZYNTHETH *---");

    AudioMemory(TOTAL_VOICES * 3);
    sgtl5000_1.enable();
    sgtl5000_1.volume(0.5);

    usbAudioOut.begin();

    setupVoices();
    MakeConnection();

    setupMidi();
}

void loop()
{
    usbMIDI.read();

    // digitalWriteFast(LED_BUILTIN, !digitalReadFast(LED_BUILTIN));

    // voices[0].PlayNote(63);
    // voices[1].PlayNote(67);
    // voices[2].PlayNote(70);
    // voices[3].PlayNote(75);
    // usbMIDI.sendNoteOn(63, 23, 1);

    // delay(500);
    // int usage     = AudioProcessorUsage();
    // int mem_usage = AudioMemoryUsageMax();
    // Serial.printf("Usage: %i%% - %i blocks\r\n", usage, mem_usage);

    // voices[0].StopNote();
    // voices[1].StopNote();
    // voices[2].StopNote();
    // voices[3].StopNote();
    // usbMIDI.sendNoteOff(63, 23, 1);

    // delay(500);
}

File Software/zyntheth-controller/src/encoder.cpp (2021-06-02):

#include "encoder.hpp"
#include "Arduino.h"

Encoder::Encoder()
    : accuSteps{}, pulseCountsCW{}, pulseCountsCCW{}, state{waiting}
{
}

Encoder::~Encoder()
{
}

bool Encoder::PushState(char newState)
{
    bool update = false;

    if (0x01 == (newState & 0x03))
    {
        if (state == waiting) state = counting;
        pulseCountsCW++;
        pulseCountsCCW = 0;
    }
    else if (0x02 == (newState & 0x03))
    {
        if (state == waiting) state = counting;
        pulseCountsCCW++;
        pulseCountsCW = 0;
    }
    else if ((0x00 == (newState & 0x03)) && (state == ready))
    {
        state = waiting;
    }
    else if ((0x03 == (newState & 0x03)) && (state == counting))
    {
        state = ready;
        if (pulseCountsCCW > DEBOUNCE_LIMIT)
        {
            accuSteps -= 1;
            state          = ready;
            update         = true;
            pulseCountsCCW = 0;
            pulseCountsCW  = 0;
        }
        else if (pulseCountsCW > DEBOUNCE_LIMIT)
        {
            accuSteps += 1;
            state          = ready;
            update         = true;
            pulseCountsCCW = 0;
            pulseCountsCW  = 0;
        }
    }
    return update;
}

int Encoder::GetSteps()
{
    int retval = accuSteps;
    Reset();
    return retval;
}

void Encoder::Reset()
{
    accuSteps = 0;
}

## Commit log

2020-06-04 Added sirst draft of kicad schematics
    [ButtonBoard.sch, ButtonController.sch, Zyntheth.kicad_pcb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]
2021-05-31 Added EncoderBoard designs and initial software projects
    [ButtonBoard.sch, ButtonController.sch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]
2021-06-03 Added MidiBoard plans. Added filter menu (ADSR).
    [Gerber_BoardOutline.GKO, Gerber_BottomLayer.GBL, Gerber_BottomSilkLayer.GBO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]
2021-06-03 Added stuff to gitignore. Added driver for IL9341_t3
2021-06-04 Added UIBoard (rev 1.1)
    Updated .gitignore to inklude picknPlace and BOM for boards
    Added Metro and an updated IL9341 library.
    [BOM_PCB_EncoderBoard.csv, BOM_PCB_MidiBoard.csv, BOM_PCB_UIBoard.csv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]
2021-06-08 Added Power and Audio boards
    Moved valuecontainer initialization to class.
    [BOM_PCB_Audio.csv, BOM_PCB_Power.csv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]
2021-06-14 Added button gfx.
    Cleanup in libs and added touch.
2021-06-14 Added STL version of all OBJ files, removed OBJ-zips
    [OBJ_PCB_UIBoard.obj, OBJ_PCB_Zynthet-Power.obj, OBJ_PCB_Zyntheth-Audio.obj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]
